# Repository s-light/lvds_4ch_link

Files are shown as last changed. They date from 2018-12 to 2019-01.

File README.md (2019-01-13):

<!--lint disable list-item-indent-->
<!--lint disable list-item-bullet-indent-->

# lvds_4ch_link
Simple LVDS 4ch Link over network-patch-cable

can be used for SPI, UART or simple GPIO

- Receiver: TI [SN65LVDT348](http://www.ti.com/product/SN65LVDT348)
- Driver: TI [SN65LVDS391](http://www.ti.com/product/SN65LVDS391)

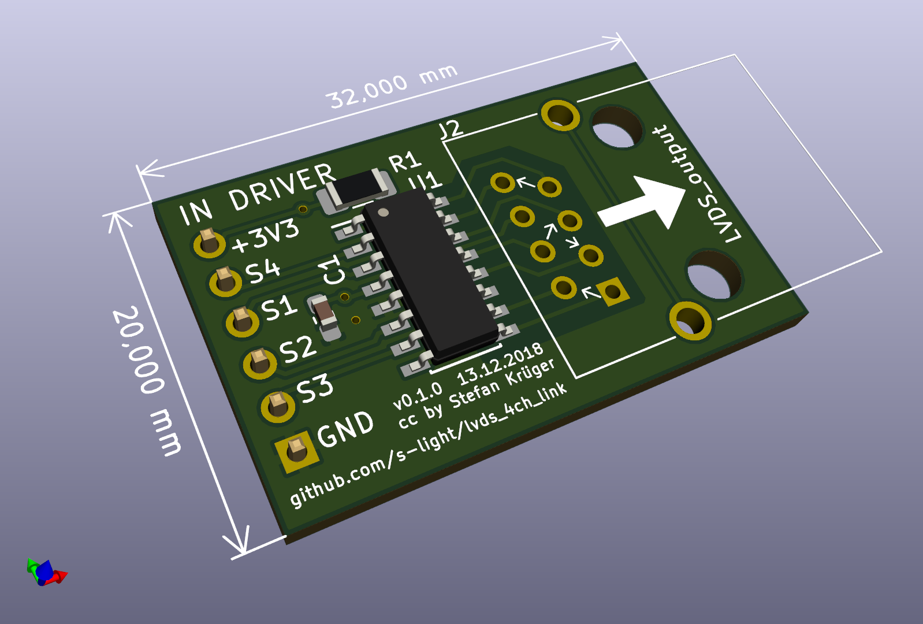
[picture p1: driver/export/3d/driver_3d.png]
Driver

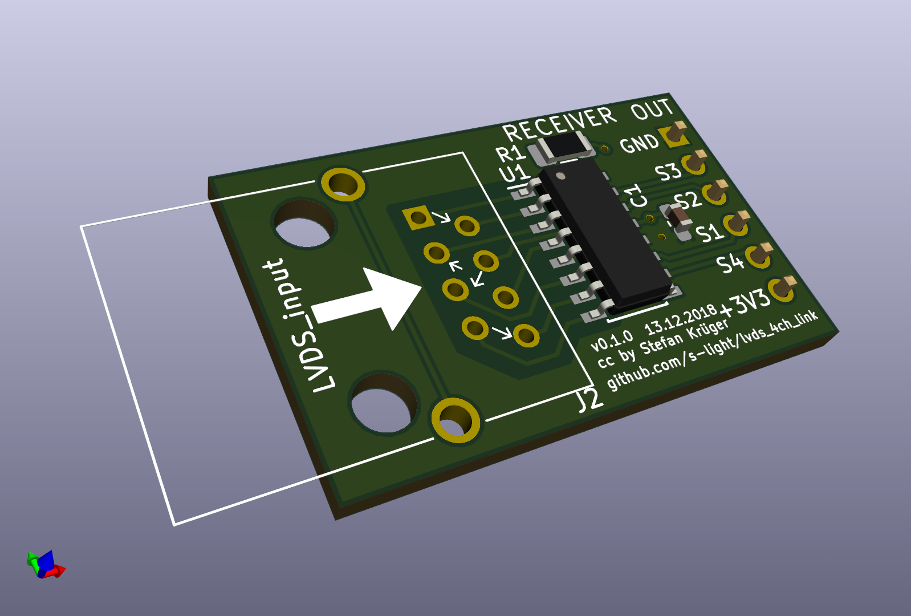
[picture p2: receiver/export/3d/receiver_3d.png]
Receiver

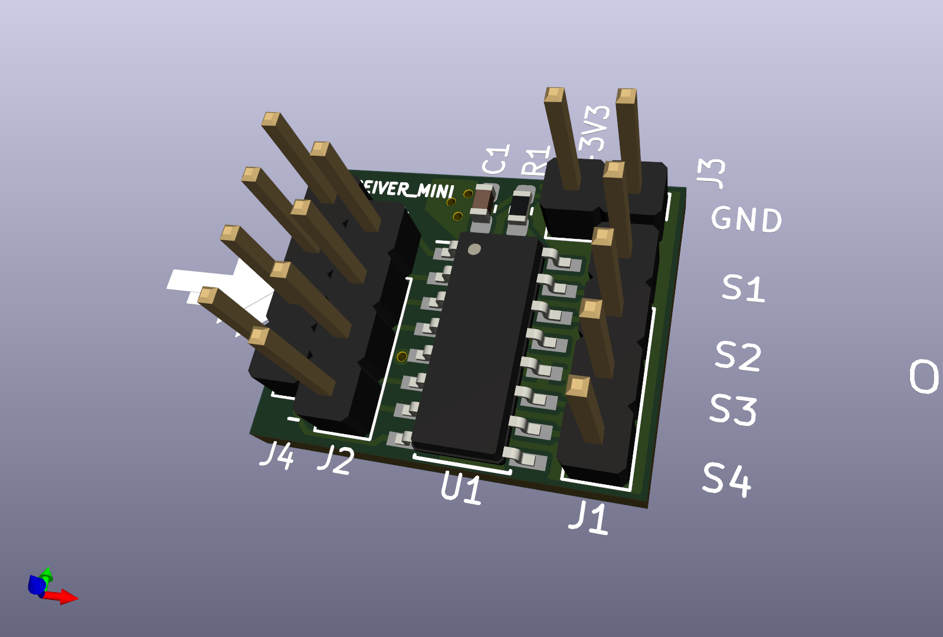
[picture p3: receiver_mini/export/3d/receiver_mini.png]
Receiver Mini

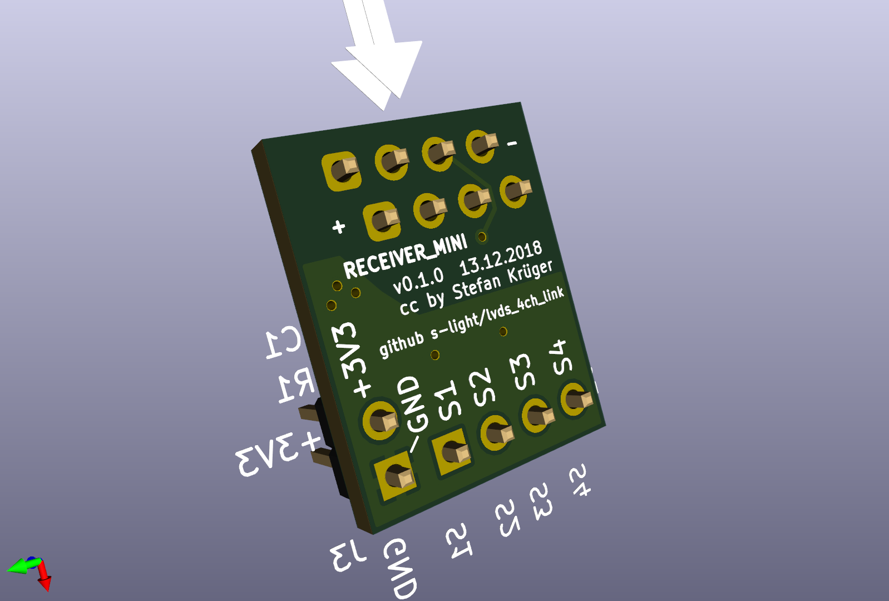
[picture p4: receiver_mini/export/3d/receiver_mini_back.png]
Receiver Mini


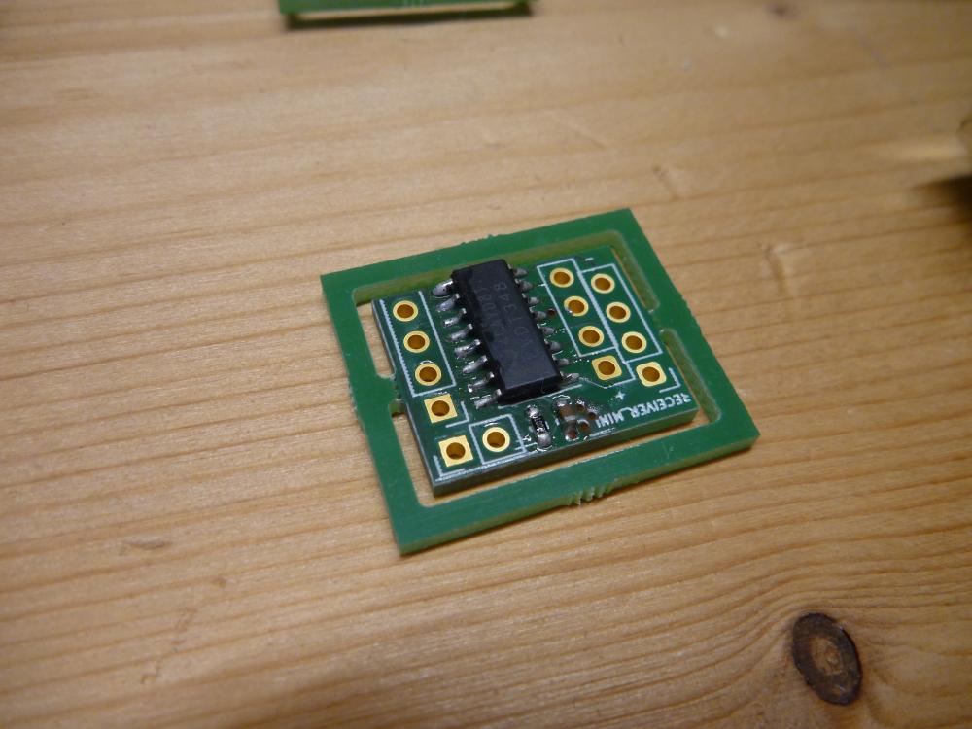
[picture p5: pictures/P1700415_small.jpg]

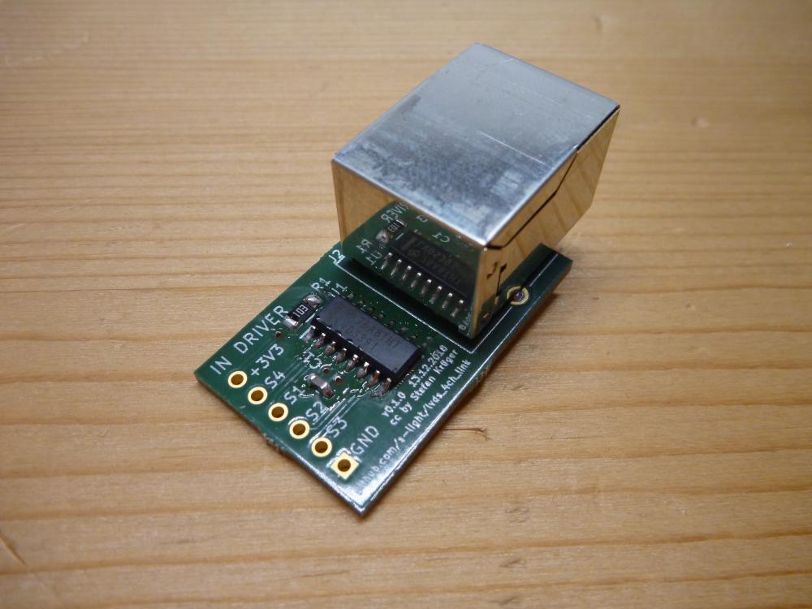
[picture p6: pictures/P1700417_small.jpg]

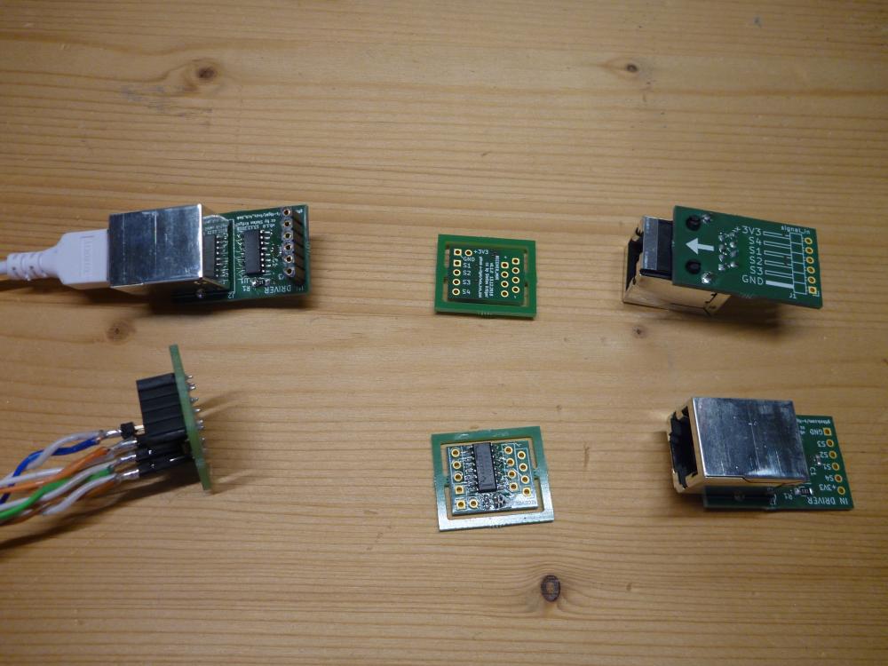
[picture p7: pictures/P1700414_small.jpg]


---

# License
<!-- license info -->
<a rel="license" href="http://creativecommons.org/licenses/by/4.0/">
    
</a>
<br />
<span xmlns:dct="http://purl.org/dc/terms/" property="dct:title">
    lvds_4ch_link
</span> by
<a xmlns:cc="http://creativecommons.org/ns#"
        href="https://github.com/s-light/lvds_4ch_link/"
        property="cc:attributionName"
        rel="cc:attributionURL">
    Stefan Krüger (s-light)
</a>
is licensed under a<br/>
<a rel="license" href="http://creativecommons.org/licenses/by/4.0/">
    Creative Commons Attribution 4.0 International License
</a>.
<!-- license info end -->

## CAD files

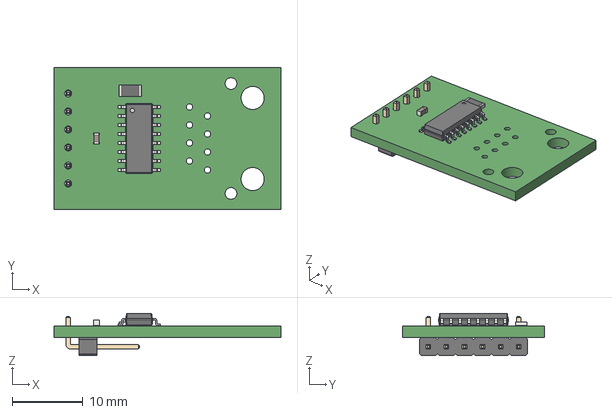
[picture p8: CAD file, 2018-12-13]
driver/export/3d/driver.step
32.0 x 20.0 x 5.99 mm

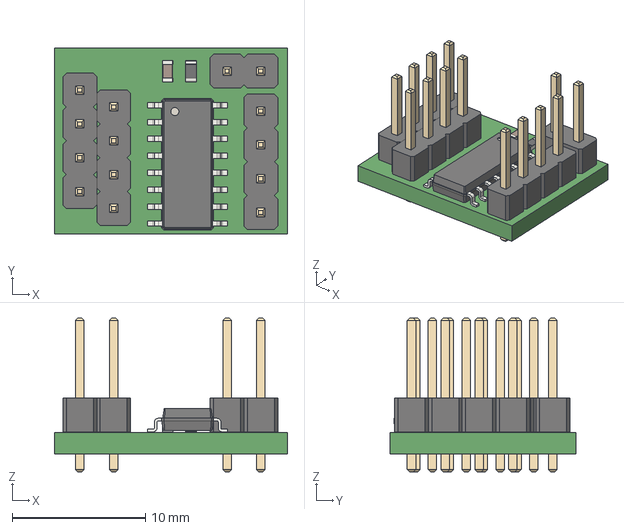
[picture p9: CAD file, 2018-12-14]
receiver_mini/export/3d/receiver_mini.step
17.5 x 14.0 x 11.5 mm

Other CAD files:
receiver/export/3d/receiver.step
receiver_mini/export/3d/receiver_mini.fcstd

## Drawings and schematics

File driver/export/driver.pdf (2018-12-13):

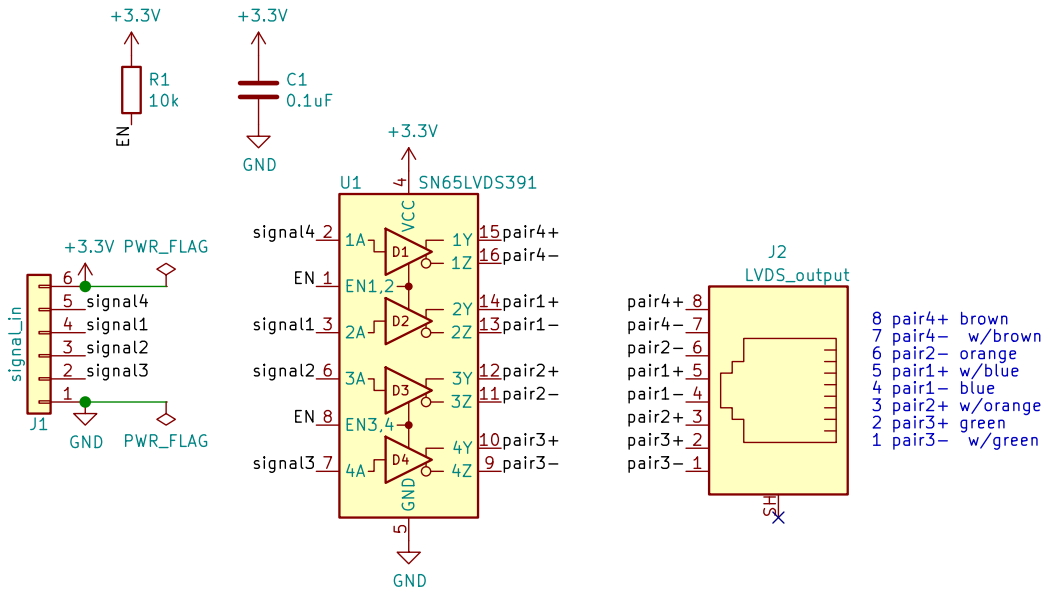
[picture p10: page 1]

Stefan Krüger CC BY Open Source Hardware

Id: 1/1 Title: LVDS 4ch Driver File: driver.sch Sheet: / s-light.eu

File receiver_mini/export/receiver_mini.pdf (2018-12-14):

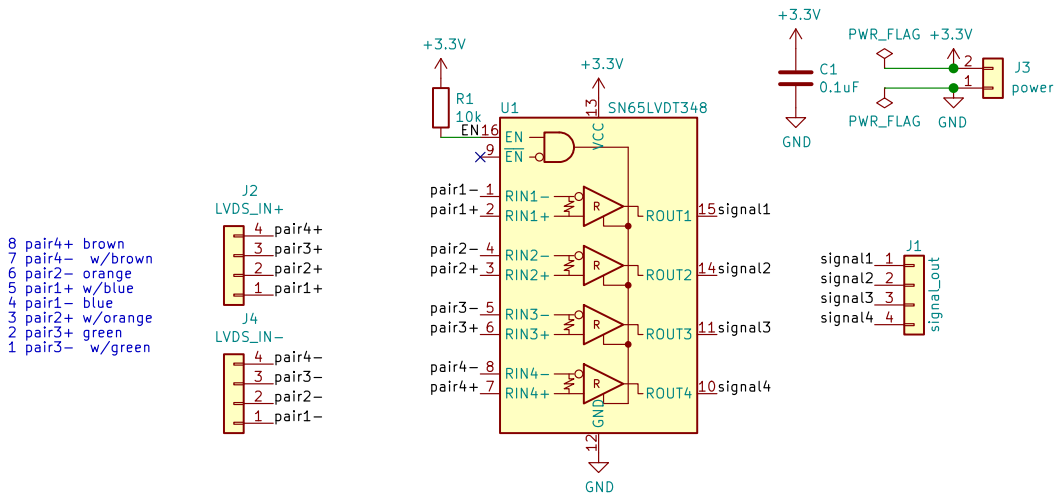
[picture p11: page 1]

Stefan Krüger CC BY Open Source Hardware

File: receiver_mini.sch Sheet: / s-light.eu

Id: 1/1 Title: LVDS 4ch Receiver Mini

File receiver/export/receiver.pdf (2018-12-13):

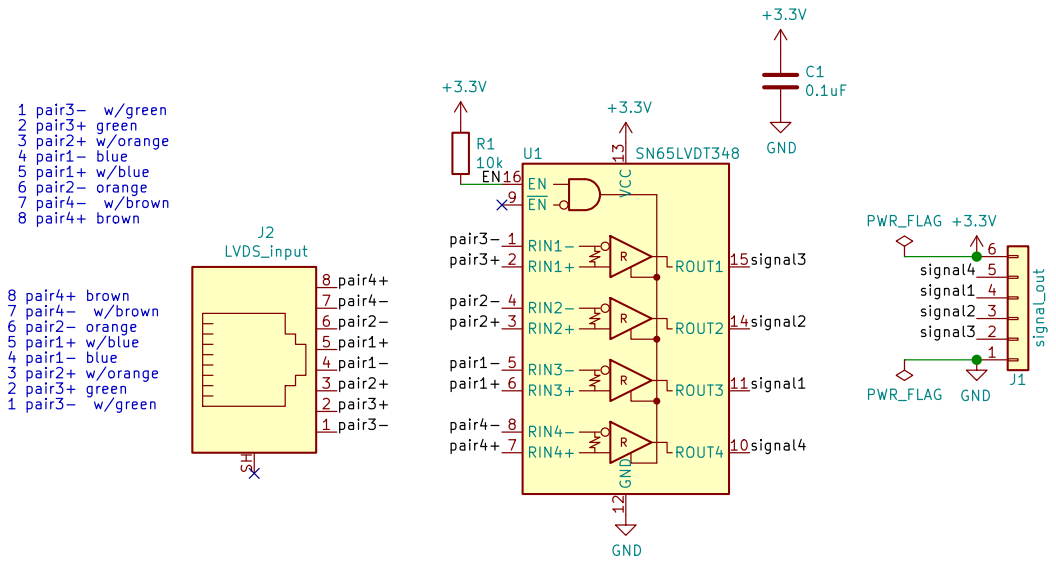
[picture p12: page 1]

Stefan Krüger CC BY Open Source Hardware

Id: 1/1 Title: LVDS 4ch Receiver File: receiver.sch Sheet: / s-light.eu

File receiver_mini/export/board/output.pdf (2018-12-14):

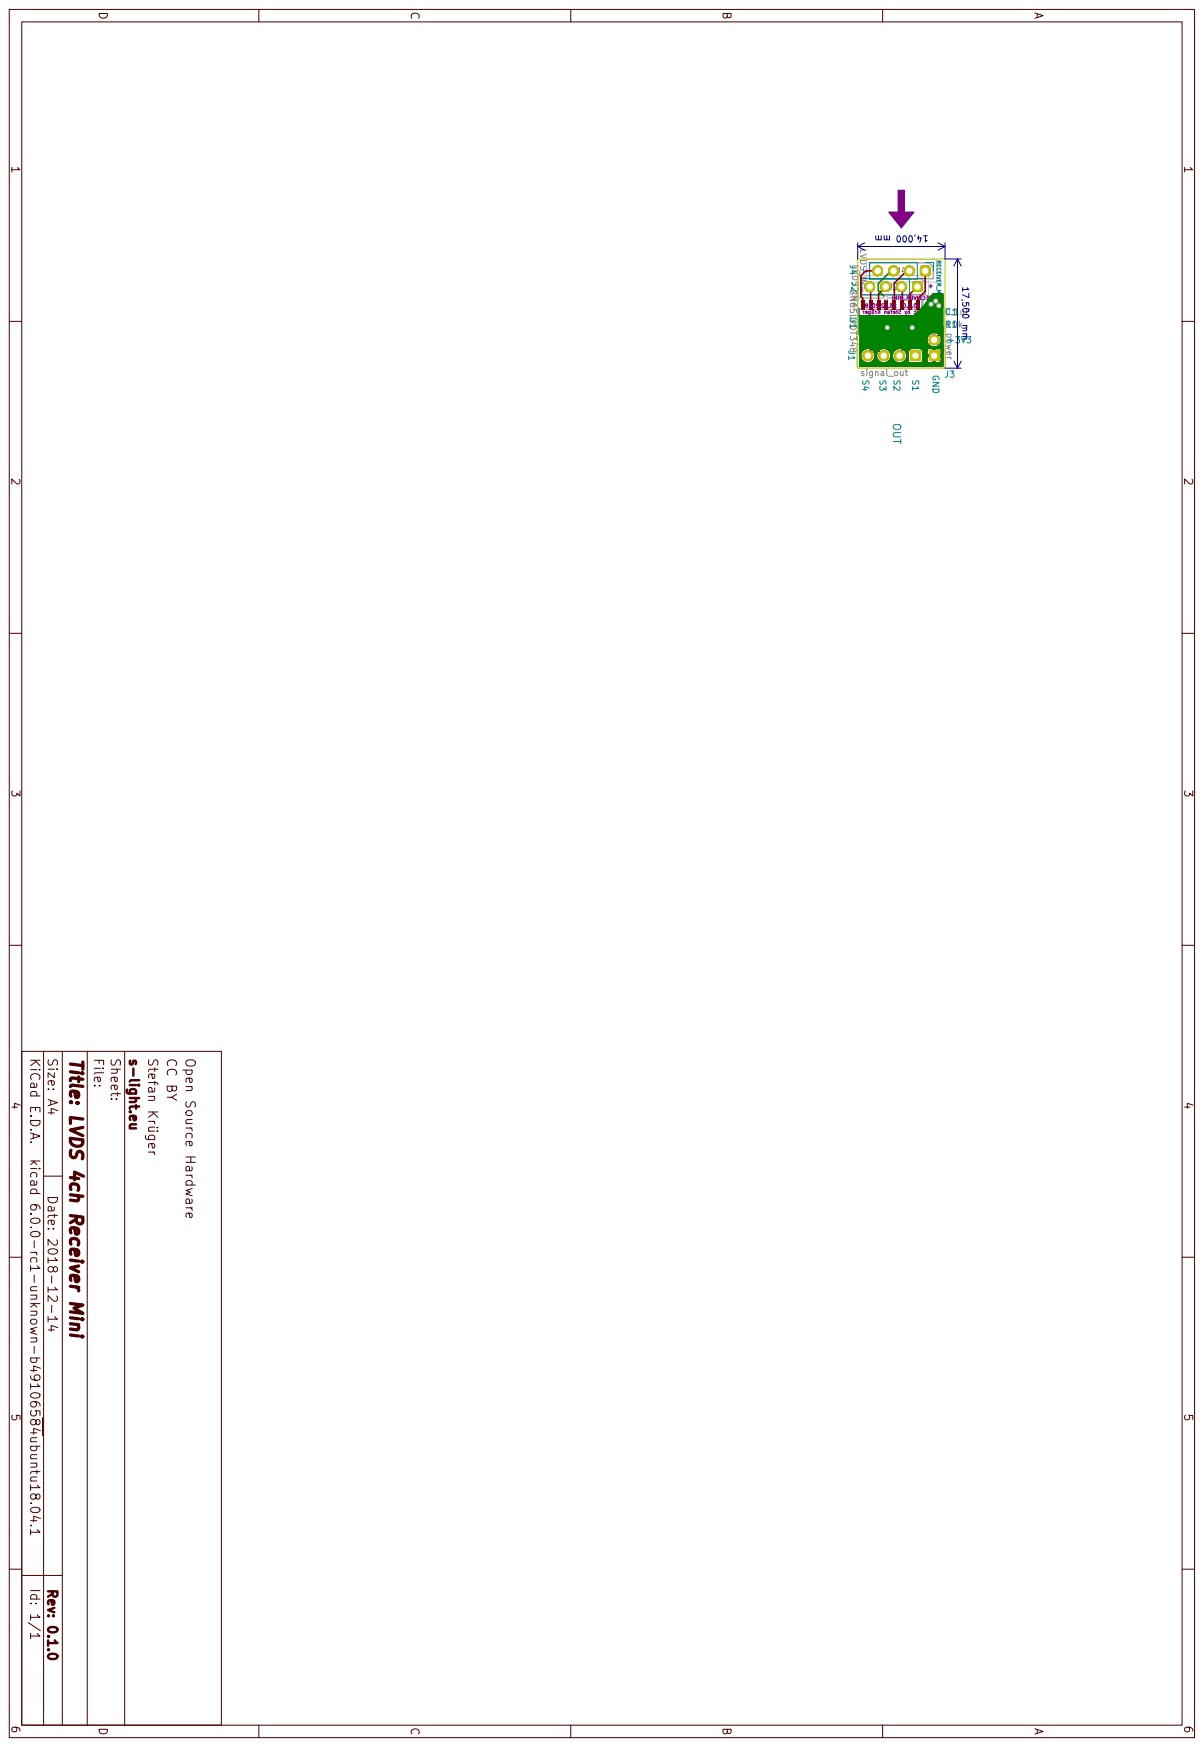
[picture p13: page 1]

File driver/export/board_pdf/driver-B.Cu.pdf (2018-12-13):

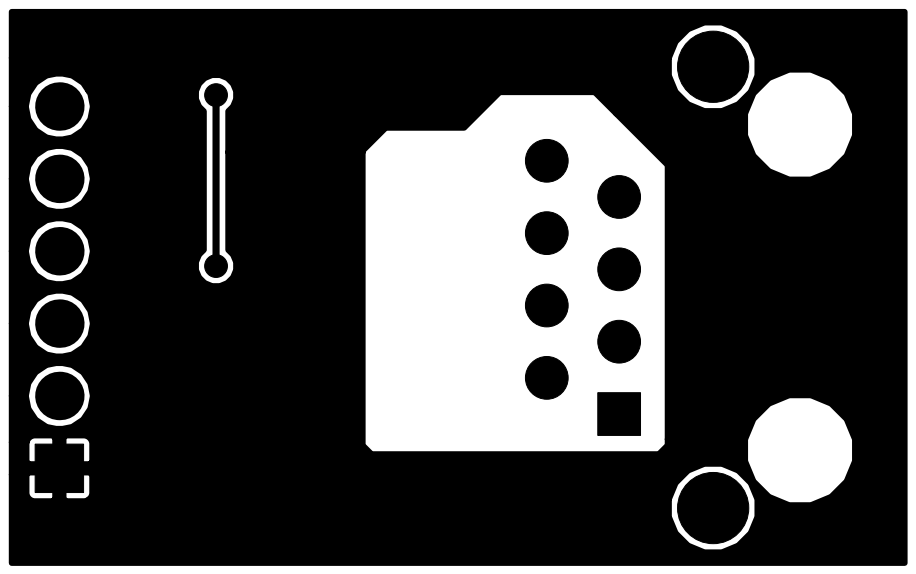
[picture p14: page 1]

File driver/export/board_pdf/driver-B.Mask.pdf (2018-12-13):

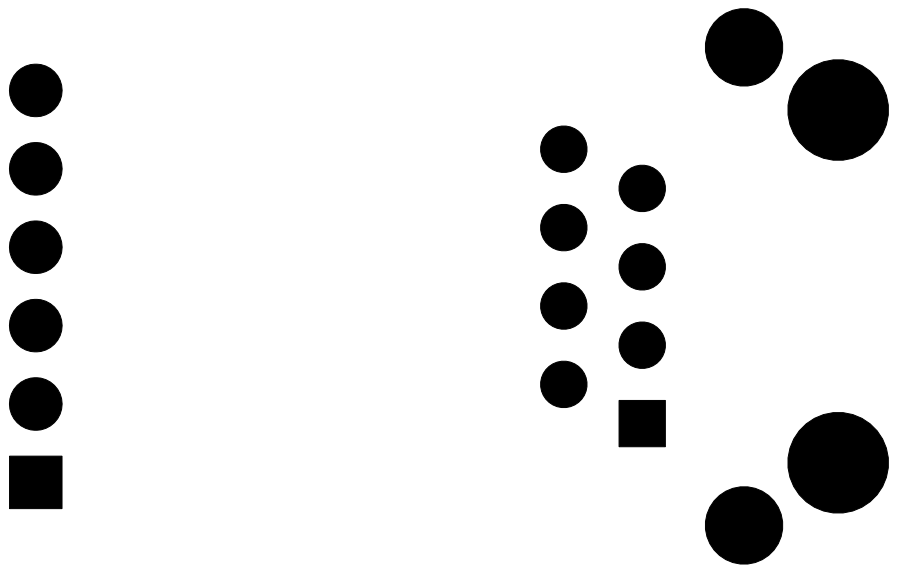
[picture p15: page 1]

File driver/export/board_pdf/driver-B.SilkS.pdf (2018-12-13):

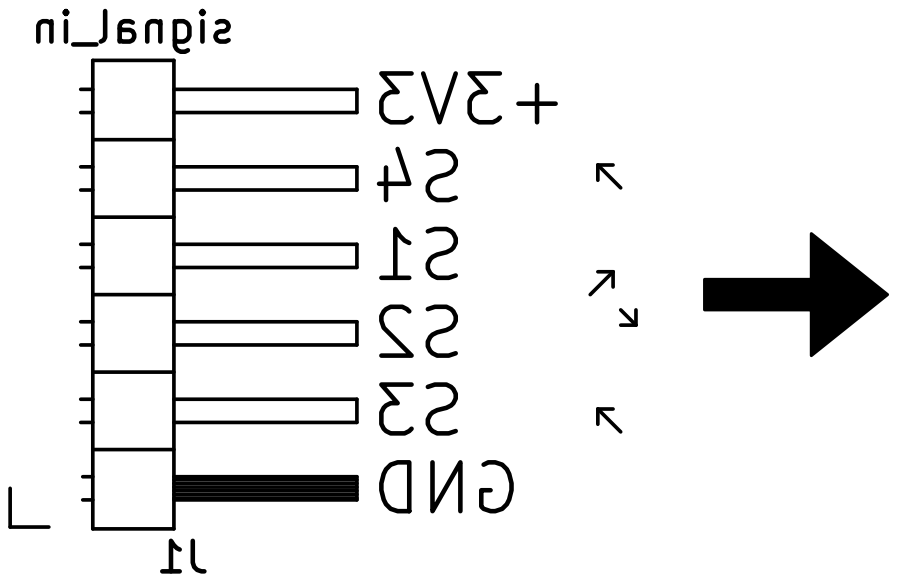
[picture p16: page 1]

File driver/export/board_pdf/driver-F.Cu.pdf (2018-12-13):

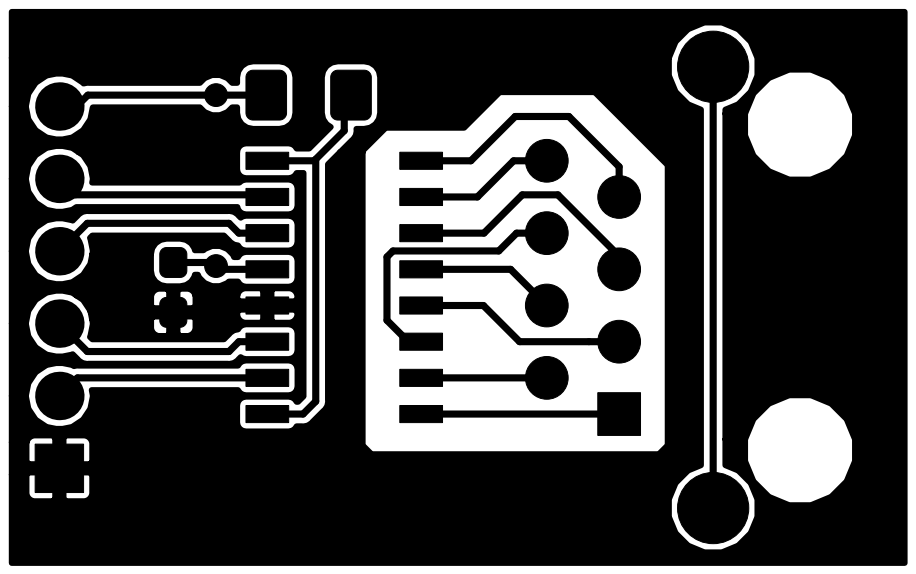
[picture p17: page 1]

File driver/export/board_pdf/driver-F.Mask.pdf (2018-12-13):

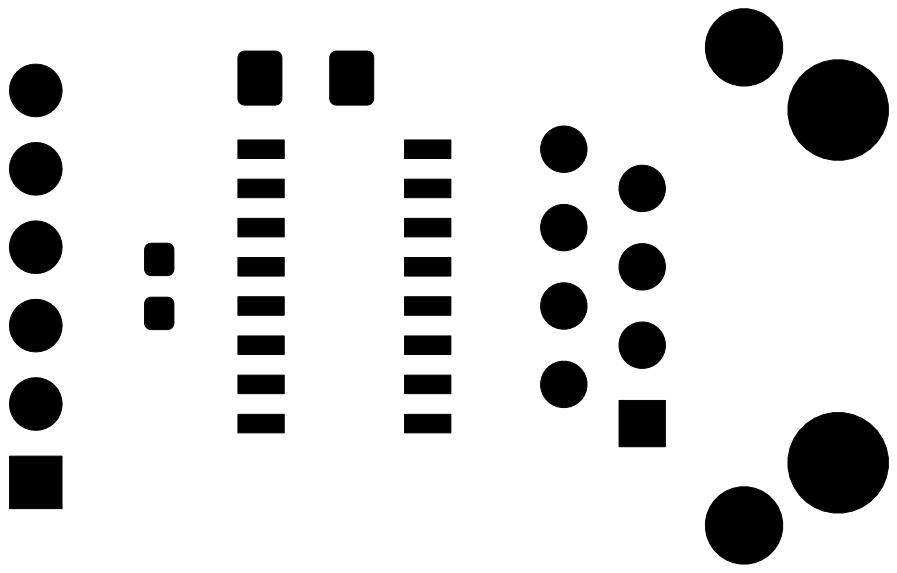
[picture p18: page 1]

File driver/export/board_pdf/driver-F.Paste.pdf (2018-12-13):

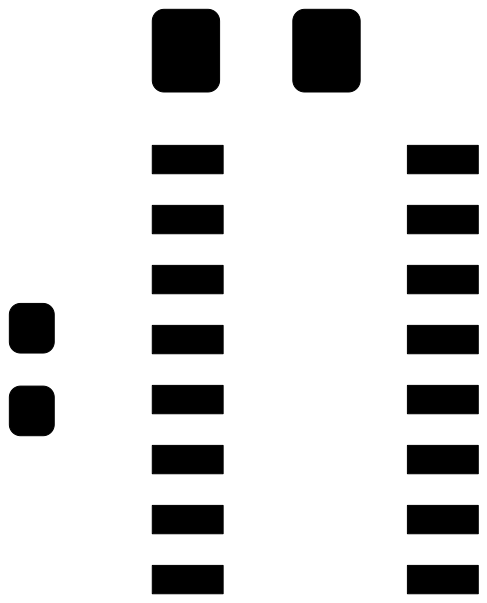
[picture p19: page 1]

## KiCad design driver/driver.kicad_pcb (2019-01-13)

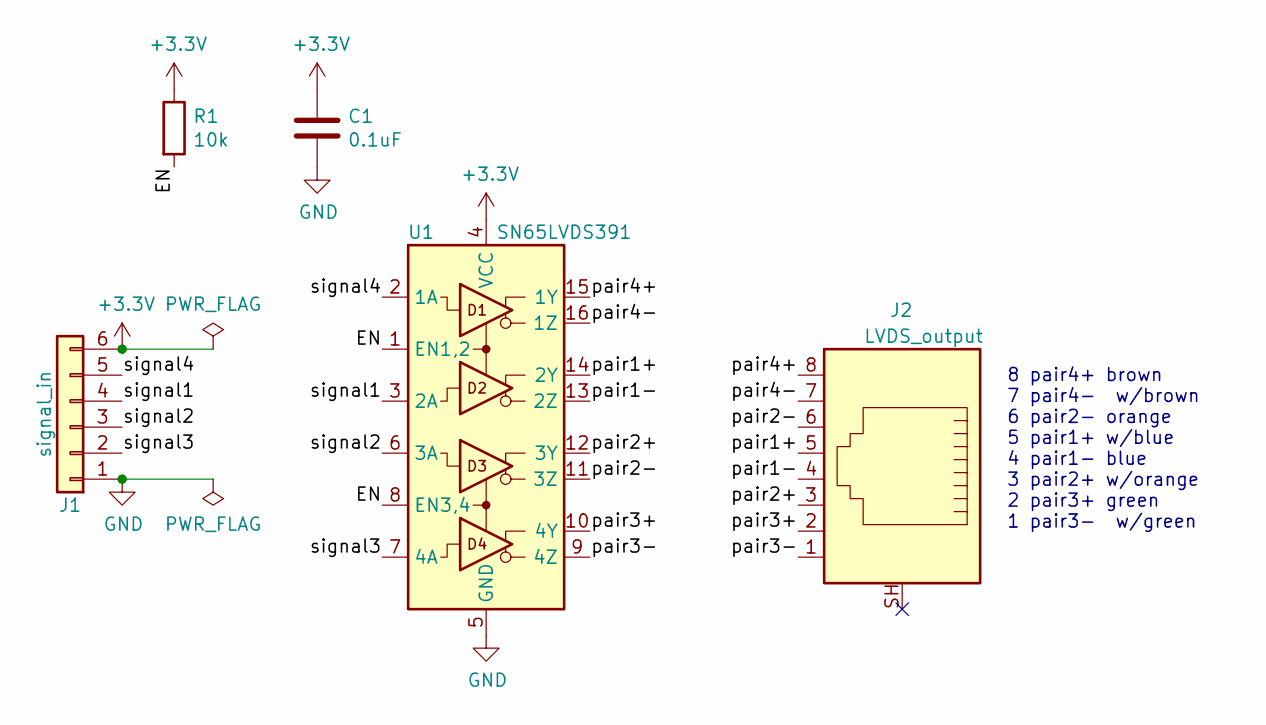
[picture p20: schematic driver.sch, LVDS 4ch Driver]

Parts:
C1: 0.1uF; C_0603_1608Metric_Pad1.05x0.95mm_HandSolder
J1: signal_in; PinHeader_1x06_P2.54mm_Horizontal
J2: LVDS_output; RJ45_Stewart_SS-6488S-A-NF
R1: 10k; R_1206_3216Metric_Pad1.42x1.75mm_HandSolder
U1: SN65LVDS391; SOIC-16_3.9x9.9mm_P1.27mm

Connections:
+3V3: C1.1, J1.6, R1.1, U1.4 (VCC)
/EN: R1.2, U1.1 (EN1,2), U1.8 (EN3,4)
/pair1+: J2.5, U1.14 (2Y)
/pair1-: J2.4, U1.13 (2Z)
/pair2+: J2.3, U1.12 (3Y)
/pair2-: J2.6, U1.11 (3Z)
/pair3+: J2.2, U1.10 (4Y)
/pair3-: J2.1, U1.9 (4Z)
/pair4+: J2.8, U1.15 (1Y)
/pair4-: J2.7, U1.16 (1Z)
/signal1: J1.4, U1.3 (2A)
/signal2: J1.3, U1.6 (3A)
/signal3: J1.2, U1.7 (4A)
/signal4: J1.5, U1.2 (1A)
GND: C1.2, J1.1, U1.5 (GND)

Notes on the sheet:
8 pair4+ brown 7 pair4- w/brown 6 pair2- orange 5 pair1+ w/blue 4 pair1- blue 3 pair2+ w/orange 2 pair3+ green 1 pair3- w/green

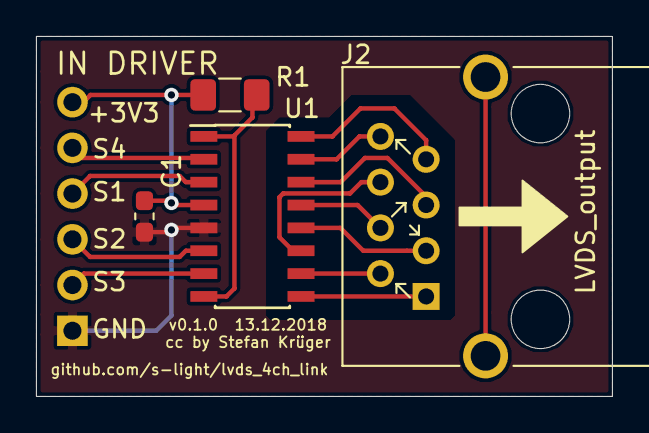
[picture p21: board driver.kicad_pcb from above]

Board: 2 copper layers, 32.0 x 20.0 mm, 5 parts (1 on the bottom side), 15 nets.

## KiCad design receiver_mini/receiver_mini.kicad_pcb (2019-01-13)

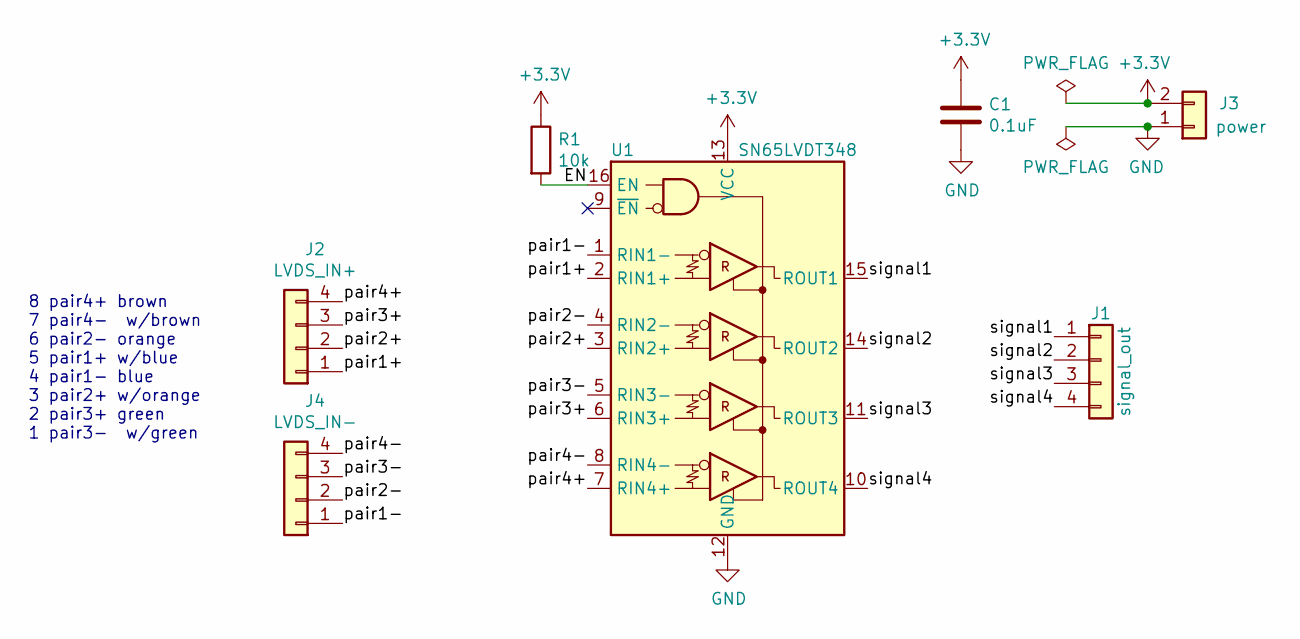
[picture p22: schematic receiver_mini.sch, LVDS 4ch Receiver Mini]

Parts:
C1: 0.1uF; C_0603_1608Metric_Pad1.05x0.95mm_HandSolder
J1: signal_out; PinHeader_1x04_P2.54mm_Vertical
J2: LVDS_IN+; PinHeader_1x04_P2.54mm_Vertical
J3: power; PinHeader_1x02_P2.54mm_Vertical
J4: LVDS_IN-; PinHeader_1x04_P2.54mm_Vertical
R1: 10k; R_0603_1608Metric_Pad1.05x0.95mm_HandSolder
U1: SN65LVDT348; SOIC-16_3.9x9.9mm_P1.27mm

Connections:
+3V3: C1.1, J3.2, R1.1, U1.13 (VCC)
/EN: R1.2, U1.16 (EN)
/pair1+: J2.1, U1.2 (RIN1+)
/pair1-: J4.1, U1.1 (RIN1-)
/pair2+: J2.2, U1.3 (RIN2+)
/pair2-: J4.2, U1.4 (RIN2-)
/pair3+: J2.3, U1.6 (RIN3+)
/pair3-: J4.3, U1.5 (RIN3-)
/pair4+: J2.4, U1.7 (RIN4+)
/pair4-: J4.4, U1.8 (RIN4-)
/signal1: J1.1, U1.15 (ROUT1)
/signal2: J1.2, U1.14 (ROUT2)
/signal3: J1.3, U1.11 (ROUT3)
/signal4: J1.4, U1.10 (ROUT4)
GND: C1.2, J3.1, U1.12 (GND)

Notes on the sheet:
8 pair4+ brown 7 pair4- w/brown 6 pair2- orange 5 pair1+ w/blue 4 pair1- blue 3 pair2+ w/orange 2 pair3+ green 1 pair3- w/green

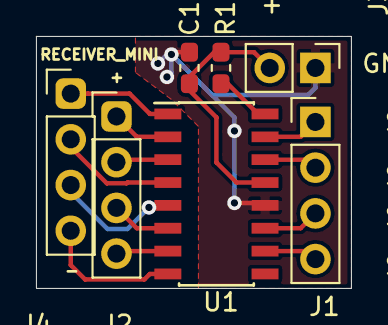
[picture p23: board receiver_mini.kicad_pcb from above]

Board: 2 copper layers, 17.5 x 14.0 mm, 7 parts (0 on the bottom side), 15 nets.

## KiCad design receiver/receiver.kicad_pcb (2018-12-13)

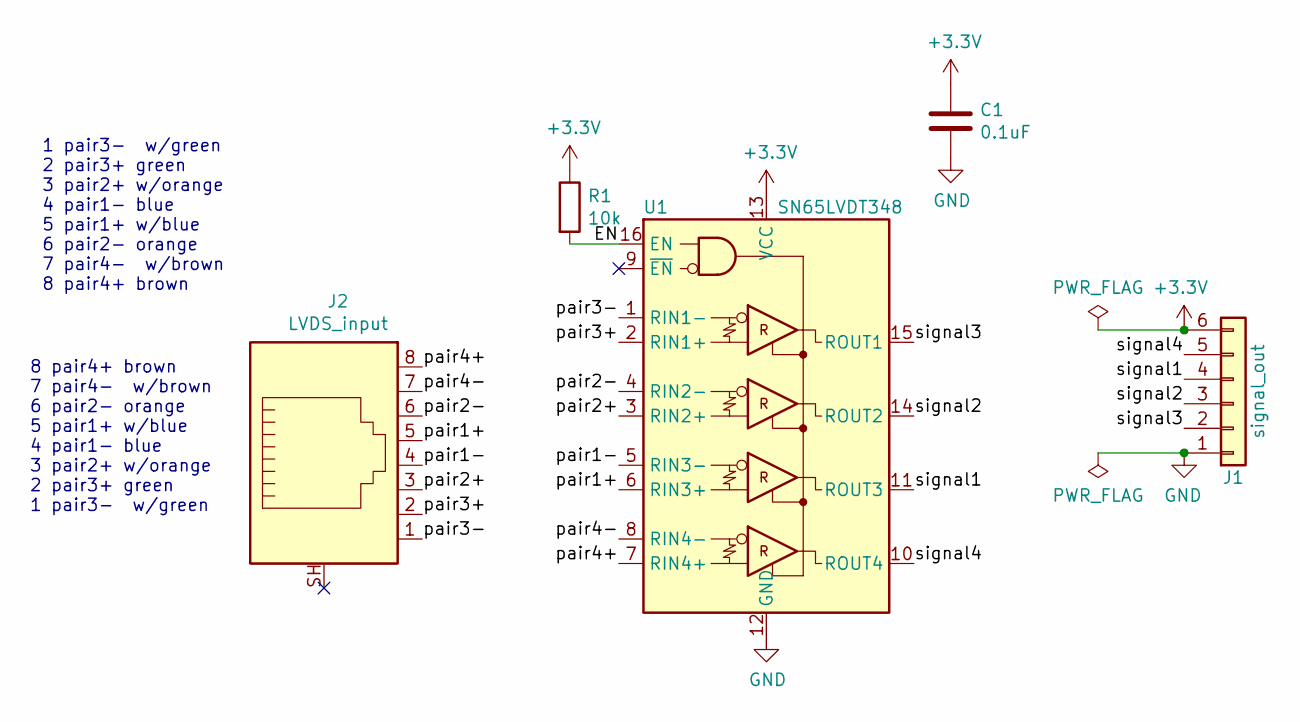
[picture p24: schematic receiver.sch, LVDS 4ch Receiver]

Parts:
C1: 0.1uF; C_0603_1608Metric_Pad1.05x0.95mm_HandSolder
J1: signal_out; PinHeader_1x06_P2.54mm_Horizontal
J2: LVDS_input; RJ45_Stewart_SS-6488S-A-NF
R1: 10k; R_1206_3216Metric_Pad1.42x1.75mm_HandSolder
U1: SN65LVDT348; SOIC-16_3.9x9.9mm_P1.27mm

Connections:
+3V3: C1.1, J1.6, R1.1, U1.13 (VCC)
/EN: R1.2, U1.16 (EN)
/pair1+: J2.5, U1.6 (RIN3+)
/pair1-: J2.4, U1.5 (RIN3-)
/pair2+: J2.3, U1.3 (RIN2+)
/pair2-: J2.6, U1.4 (RIN2-)
/pair3+: J2.2, U1.2 (RIN1+)
/pair3-: J2.1, U1.1 (RIN1-)
/pair4+: J2.8, U1.7 (RIN4+)
/pair4-: J2.7, U1.8 (RIN4-)
/signal1: J1.4, U1.11 (ROUT3)
/signal2: J1.3, U1.14 (ROUT2)
/signal3: J1.2, U1.15 (ROUT1)
/signal4: J1.5, U1.10 (ROUT4)
GND: C1.2, J1.1, U1.12 (GND)

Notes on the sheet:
1 pair3- w/green 2 pair3+ green 3 pair2+ w/orange 4 pair1- blue 5 pair1+ w/blue 6 pair2- orange 7 pair4- w/brown 8 pair4+ brown
8 pair4+ brown 7 pair4- w/brown 6 pair2- orange 5 pair1+ w/blue 4 pair1- blue 3 pair2+ w/orange 2 pair3+ green 1 pair3- w/green

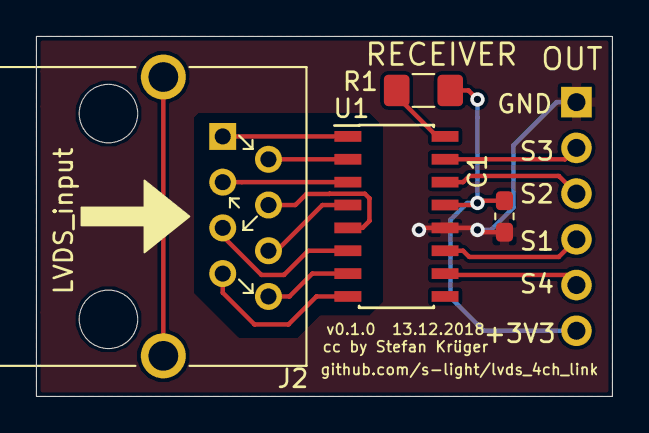
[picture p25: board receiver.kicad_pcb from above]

Board: 2 copper layers, 32.0 x 20.0 mm, 5 parts (1 on the bottom side), 15 nets.

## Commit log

2018-12-13 prepared receiver
    [receiver.kicad_pcb, receiver.sch]
2018-12-13 prepaired link
    [receiver.sch]
2018-12-13 prepare driver
    [driver.kicad_pcb, driver.sch]
2018-12-13 basic placement + added pullup for EN
    [receiver.kicad_pcb, receiver.sch]
2018-12-13 changed to correct RJ45-Plug
    [driver.kicad_pcb, driver.sch]
2018-12-13 Driver finalized
    [driver.kicad_pcb, driver.sch]
2018-12-14 added receiver_mini
    [receiver_mini.kicad_pcb, receiver_mini.sch, receiver_mini.step]
2018-12-14 added 3d model simplified
    [receiver_mini.fcstd]
2019-01-13 better readability in pcb
    [receiver_mini.kicad_pcb]
2019-01-13 better readabillity in pcb
    [driver.kicad_pcb]

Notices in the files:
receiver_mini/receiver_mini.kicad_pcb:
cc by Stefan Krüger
